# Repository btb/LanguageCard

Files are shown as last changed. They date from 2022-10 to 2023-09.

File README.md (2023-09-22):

# LanguageCard
 An Apple II Language Card. Based on a design by [iz8dwf](https://youtu.be/1KPIAoO1dTU)

[Interactive BOM](https://btb.github.io/LanguageCard/bom/LanguageCard_3.html)

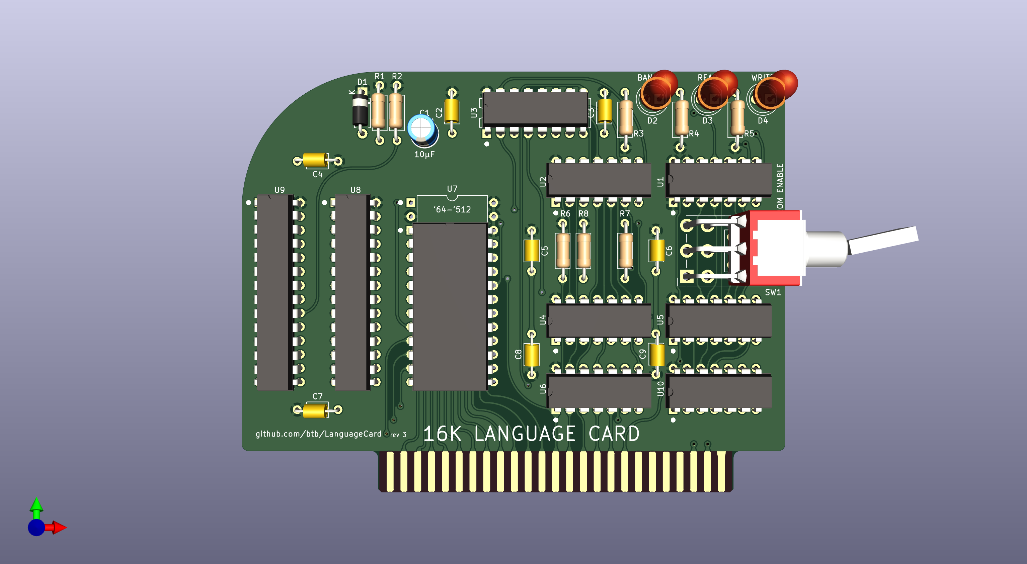
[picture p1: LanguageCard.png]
image info


## Description

This is a simple "language card" for the Apple II and II+, which expands the system from 48K to 64K by means of 16K of RAM, switchable into the address space normally used by the system firmware. That's two banks of 4K in the D0-D8 space, and one bank of 8K in the E0-F8 space. The C0-C8 space is not touched.

It uses static RAM so there is no need for the ribbon cable connecting it to the logic board that the original language cards had.

Like the original language cards, it can also contain a chip that will be used to replace the F8 ROM on your logic board. Additionally, you can enable or disable this replacement ROM with a switch or jumpers. If configured correctly, you can put two different F8 ROM images on a single chip and switch back and forth between them.

## Build Notes

### R3, R4, R5

Use higher resistance for	high-efficiency LEDs, e.g. 3.3K

### U8 and U9

Any narrow 8KBx8	static RAM can be used.	ex: 5C6408, Cy7C185, TC5588

### U7

Optional. 2K or larger	(E)EPROM for overriding the	logic board's F8 ROM. Enable	using SW1 or JP1.

### SW1

Optional Toggle switch. Miniature, Sub-miniature, or Ultra-miniature, right angle, SPDT. (Sub, Ultra-mini use JP1 pads)

An SPST switch which only closes the outer two pin positions can also work if you short JP3. 

To switch between two different F8 ROM images on a single 4K or greater chip, short JP2 and use a	DPDT switch instead - must be a three-position center OFF switch (ON-OFF-ON) in order to disable the card ROM and use the logic board F8 ROM.

### JP1

Enable and select which F8 ROM to use (if not using SW1)

| | |
|-|-|
|6|5|
|4|3|
|2|1|

No Jumpers: Card ROM disabled

#### Using a single ROM image:

JP2 open, Jumper on pins 1,3 (lower right): Card ROM enabled

#### Using two ROM images on a 4K or larger ROM:

JP2 shorted, Jumper on pins 1,3 (lower right) and 2,4 (lower left): Upper ROM image enabled (A11 high)

JP2 shorted, Jumper on pins 3,5 (upper right) and 4,6 (upper left): Lower ROM image enabled (A11 low)

### Solder Jumper JP2
Short, and install DPDT switch	(or use pair of jumpers as above) for	ability to select two different F8	ROM images on a single (4K or larger) ROM. 

### Solder Jumper JP3
Short if using an SPST switch	that only connects outer two pins

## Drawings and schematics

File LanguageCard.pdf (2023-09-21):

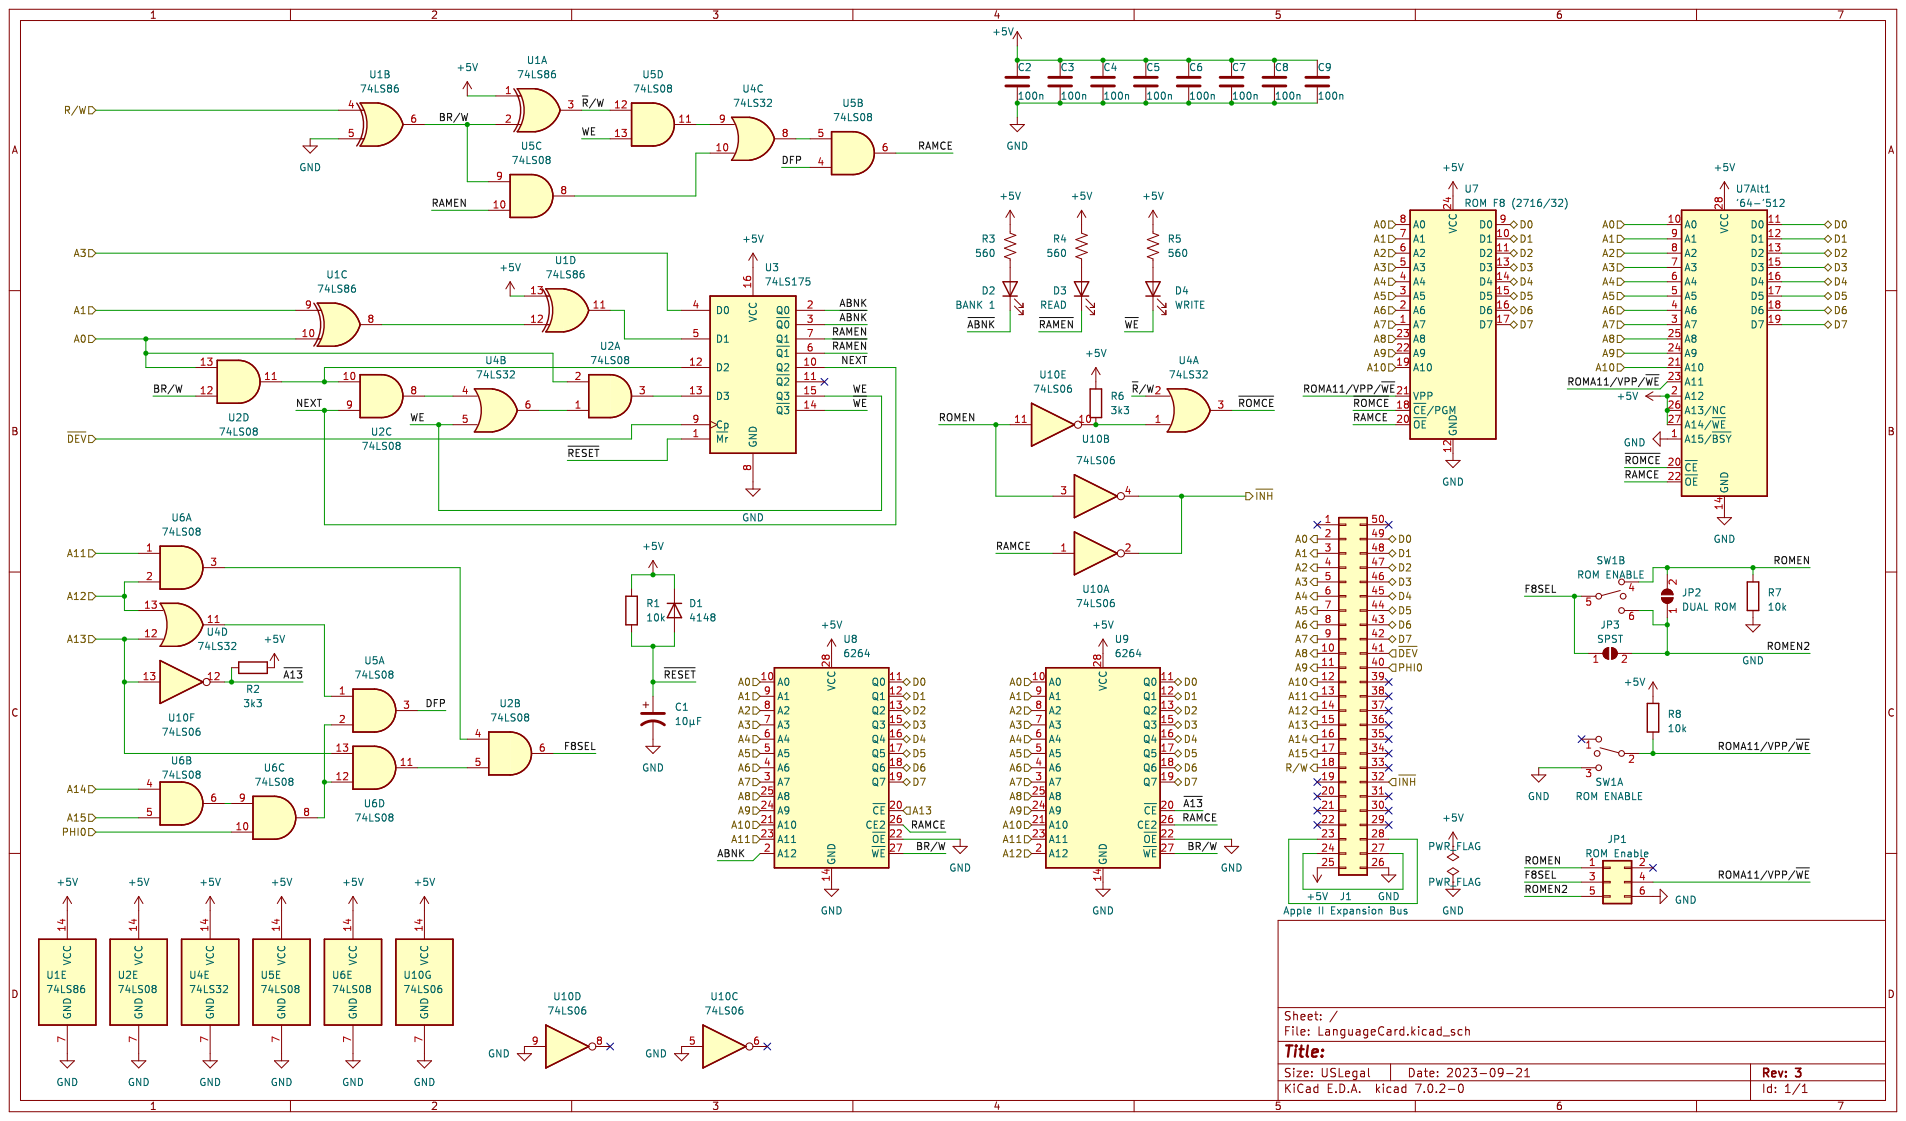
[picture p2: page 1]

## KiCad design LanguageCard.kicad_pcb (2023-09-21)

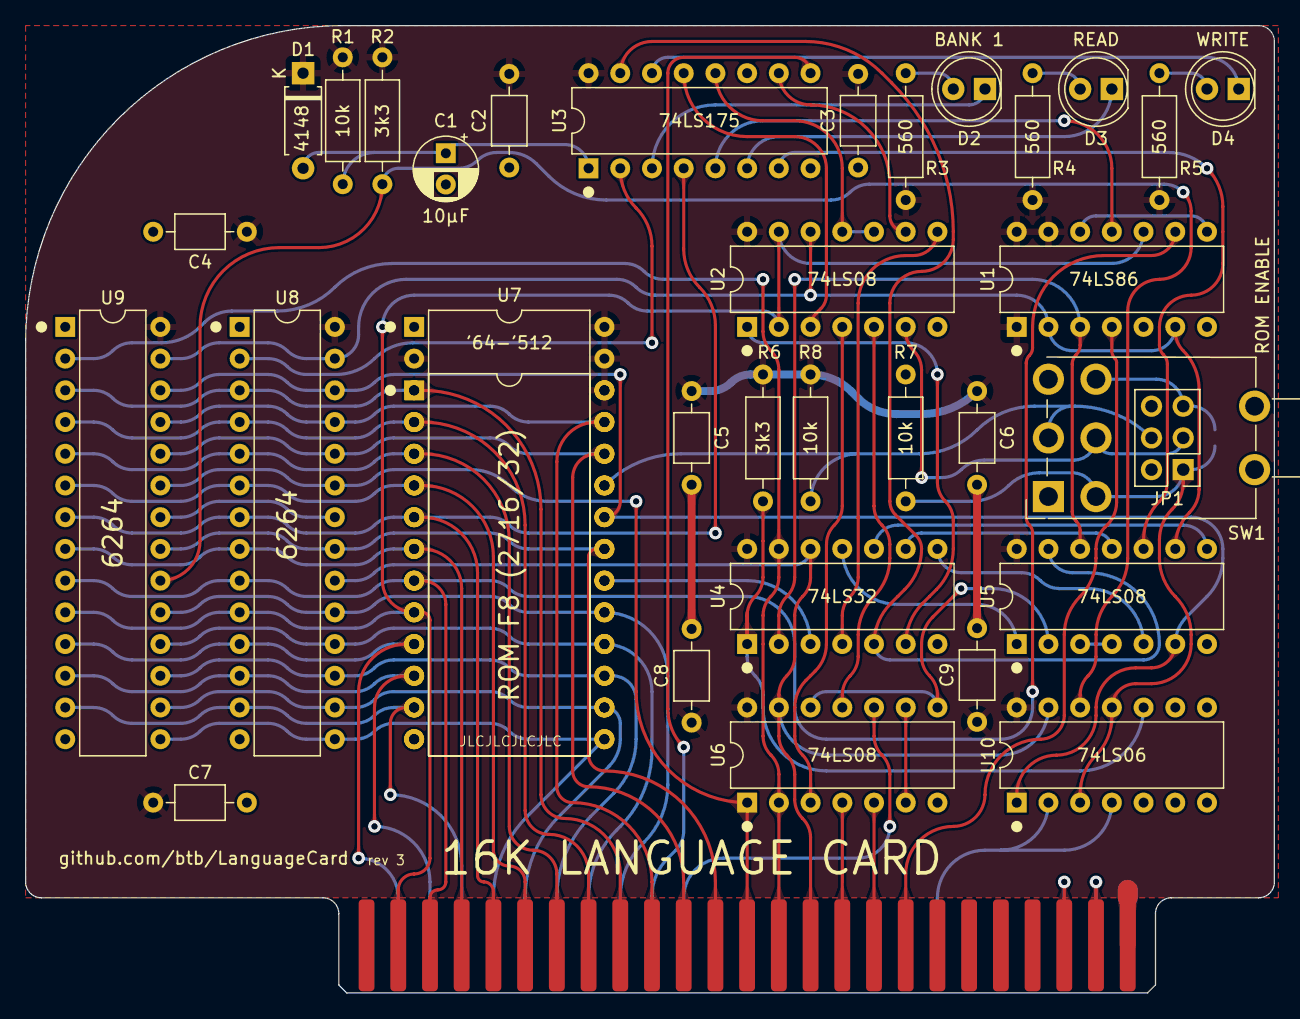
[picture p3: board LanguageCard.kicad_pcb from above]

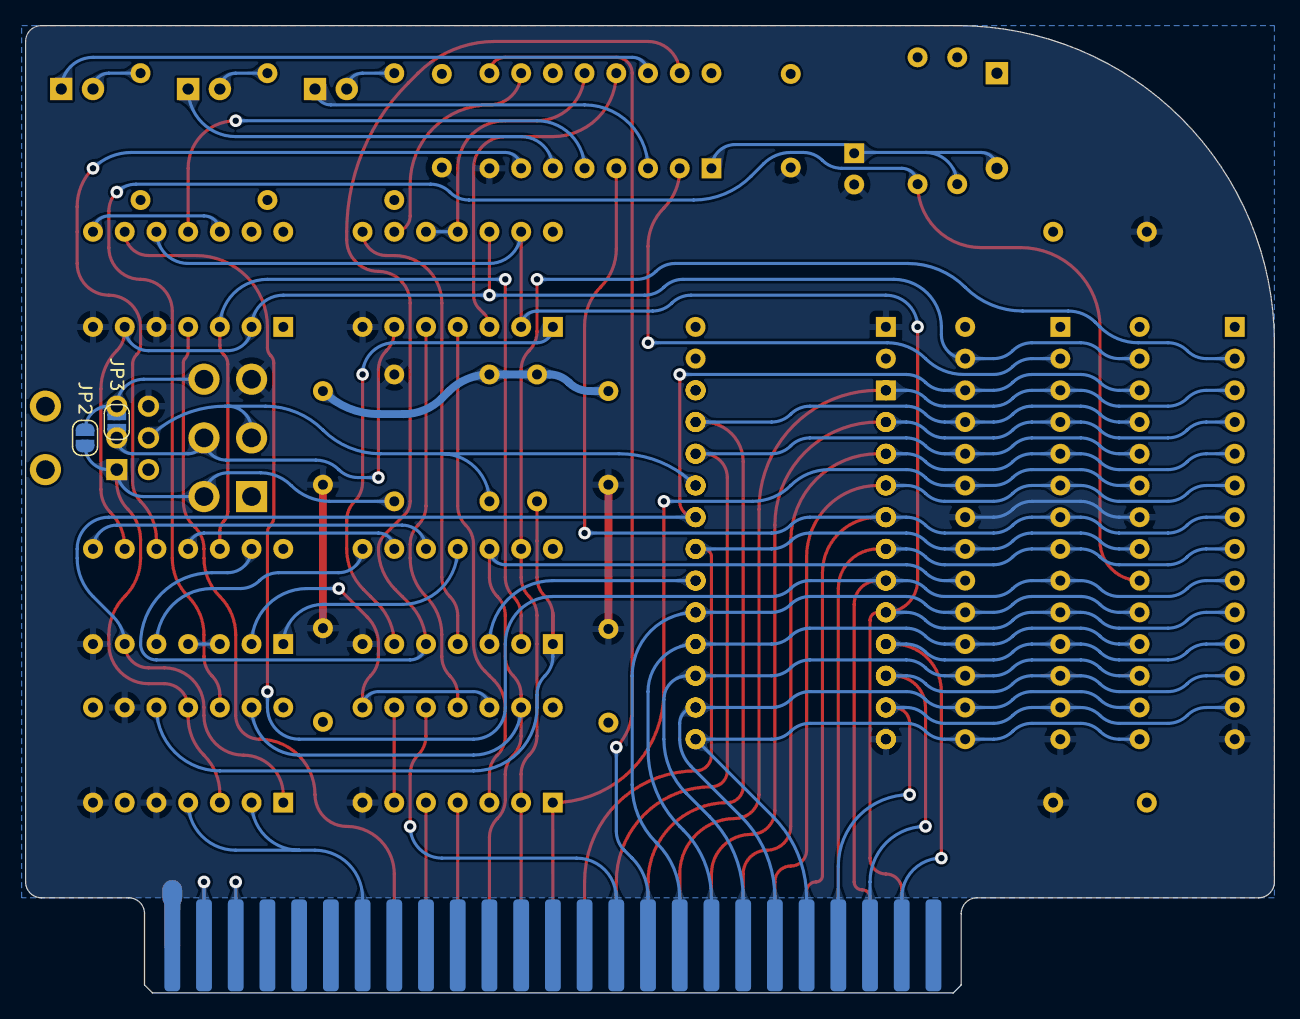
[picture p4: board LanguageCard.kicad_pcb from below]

Board: 2 copper layers, 100.0 x 77.5 mm, 37 parts (2 on the bottom side), 68 nets.

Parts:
C1: 10μF; CP_Radial_D5.0mm_P2.50mm
C2, C3, C4, C5, C6, C7, C8, C9: 100n; C_Axial_L3.8mm_D2.6mm_P7.50mm_Horizontal
D1: 4148; D_A-405_P7.62mm_Horizontal
D2: BANK 1; LED_D5.0mm
D3: READ; LED_D5.0mm
D4: WRITE; LED_D5.0mm
J1: Apple II Expansion Bus; Apple II Expansion Edge Connector
JP1: ROM Enable; PinHeader_2x03_P2.54mm_Vertical
JP2: DUAL ROM; SolderJumper-2_P1.3mm_Open_RoundedPad1.0x1.5mm
JP3: SPST; SolderJumper-2_P1.3mm_Open_RoundedPad1.0x1.5mm
R1, R7, R8: 10k; R_Axial_DIN0207_L6.3mm_D2.5mm_P10.16mm_Horizontal
R2, R6: 3k3; R_Axial_DIN0207_L6.3mm_D2.5mm_P10.16mm_Horizontal
R3, R4, R5: 560; R_Axial_DIN0207_L6.3mm_D2.5mm_P10.16mm_Horizontal
SW1: ROM ENABLE; SW_Lever_2P2T_Alcoswitch_AE203SD1
U1: 74LS86; DIP-14_W7.62mm
U2, U5, U6: 74LS08; DIP-14_W7.62mm
U3: 74LS175; DIP-16_W7.62mm
U4: 74LS32; DIP-14_W7.62mm
U7: ROM F8 (2716/32); DIP-24_W15.24mm
U7Alt1: '64-'512; DIP-28_W15.24mm
U8, U9: 6264; DIP-28_W7.62mm
U10: 74LS06; DIP-14_W7.62mm

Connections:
+5V: C2.2, C3.2, C4.1, C5.1, C6.1, C7.1, C8.1, C9.1, D1.1 (K), J1.25, R1.1, R2.2, R3.2, R4.2, R5.2, R6.2, R8.2, U1.1, U1.13, U1.14 (VCC), U2.14 (VCC), U3.16 (VCC), U4.14 (VCC), U5.14 (VCC), U6.14 (VCC), U7.24 (VCC), U7Alt1.2 (A12), U7Alt1.26 (A13/NC), U7Alt1.27 (A14/~WE), U7Alt1.28 (VCC), U8.28 (VCC), U9.28 (VCC), U10.14 (VCC)
/A0: J1.2, U1.10, U2.2, U2.13, U7.8 (A0), U7Alt1.10 (A0), U8.10 (A0), U9.10 (A0)
/A1: J1.3, U1.9, U7.7 (A1), U7Alt1.9 (A1), U8.9 (A1), U9.9 (A1)
/A2: J1.4, U7.6 (A2), U7Alt1.8 (A2), U8.8 (A2), U9.8 (A2)
/A3: J1.5, U3.4 (D0), U7.5 (A3), U7Alt1.7 (A3), U8.7 (A3), U9.7 (A3)
/A4: J1.6, U7.4 (A4), U7Alt1.6 (A4), U8.6 (A4), U9.6 (A4)
/A5: J1.7, U7.3 (A5), U7Alt1.5 (A5), U8.5 (A5), U9.5 (A5)
/A6: J1.8, U7.2 (A6), U7Alt1.4 (A6), U8.4 (A6), U9.4 (A6)
/A7: J1.9, U7.1 (A7), U7Alt1.3 (A7), U8.3 (A7), U9.3 (A7)
/A8: J1.10, U7.23 (A8), U7Alt1.25 (A8), U8.25 (A8), U9.25 (A8)
/A9: J1.11, U7.22 (A9), U7Alt1.24 (A9), U8.24 (A9), U9.24 (A9)
/A10: J1.12, U7.19 (A10), U7Alt1.21 (A10), U8.21 (A10), U9.21 (A10)
/A11: J1.13, U6.1, U8.23 (A11), U9.23 (A11)
/A12: J1.14, U4.13, U6.2, U9.2 (A12)
/A13: J1.15, U4.12, U6.13, U8.20 (~CE), U10.13
/A14: J1.16, U6.4
/A15: J1.17, U6.5
/ABNK: U3.2 (Q0), U8.2 (A12)
/BR/W: U1.2, U1.6, U2.12, U5.9, U8.27 (~WE), U9.27 (~WE)
/D0: J1.49, U7.9 (D0), U7Alt1.11 (D0), U8.11 (Q0), U9.11 (Q0)
/D1: J1.48, U7.10 (D1), U7Alt1.12 (D1), U8.12 (Q1), U9.12 (Q1)
/D2: J1.47, U7.11 (D2), U7Alt1.13 (D2), U8.13 (Q2), U9.13 (Q2)
/D3: J1.46, U7.13 (D3), U7Alt1.15 (D3), U8.15 (Q3), U9.15 (Q3)
/D4: J1.45, U7.14 (D4), U7Alt1.16 (D4), U8.16 (Q4), U9.16 (Q4)
/D5: J1.44, U7.15 (D5), U7Alt1.17 (D5), U8.17 (Q5), U9.17 (Q5)
/D6: J1.43, U7.16 (D6), U7Alt1.18 (D6), U8.18 (Q6), U9.18 (Q6)
/D7: J1.42, U7.17 (D7), U7Alt1.19 (D7), U8.19 (Q7), U9.19 (Q7)
/DFP: U5.3, U5.4
/F8SEL: JP1.3, JP3.1 (A), SW1.5 (B), U2.6
/NEXT: U2.9, U3.10 (Q2)
/PHI0: J1.40, U6.10
/RAMCE: U5.6, U7.20 (~OE), U7Alt1.22 (~OE), U8.26 (CE2), U9.26 (CE2), U10.1
/RAMEN: U3.7 (Q1), U5.10
/ROMA11/VPP/~WE: JP1.4, R8.1, SW1.2 (B), U7.21 (VPP), U7Alt1.23 (A11)
/ROMEN: JP1.1, JP2.2 (B), R7.2, SW1.4 (A), U10.3, U10.11
/ROMEN2: JP1.5, JP2.1 (A), JP3.2 (B), SW1.6 (C)
/R/W: J1.18, U1.4
/WE: U3.15 (Q3), U4.5, U5.13
/~A13: R2.1, U9.20 (~CE), U10.12
/~ABNK: D2.1 (K), U3.3 (~Q0)
/~DEV: J1.41, U3.9 (Cp)
/~INH: J1.32, U10.2, U10.4
/~RAMEN: D3.1 (K), U3.6 (~Q1)
/~RESET: C1.1, D1.2 (A), R1.2, U3.1 (~Mr)
/~ROMCE: U4.3, U7.18 (~CE/PGM), U7Alt1.20 (~CE)
/~R/W: U1.3, U4.2, U5.12
/~WE: D4.1 (K), U3.14 (~Q3)
GND: C1.2, C2.1, C3.1, C4.2, C5.2, C6.2, C7.2, C8.2, C9.2, J1.26, JP1.6, R7.1, SW1.3 (C), U1.5, U1.7 (GND), U2.7 (GND), U3.8 (GND), U4.7 (GND), U5.7 (GND), U6.7 (GND), U7.12 (GND), U7Alt1.1 (A15/~BSY), U7Alt1.14 (GND), U8.14 (GND), U8.22 (~OE), U9.14 (GND), U9.22 (~OE), U10.5, U10.7 (GND), U10.9
unnamed: D2.2 (A), R3.1
unnamed: D3.2 (A), R4.1
unnamed: D4.2 (A), R5.1
unnamed: J1.23, J1.28
unnamed: J1.24, J1.27
unnamed: R6.1, U4.1, U10.10
unnamed: U1.8, U1.12
unnamed: U2.1, U4.6
unnamed: U2.4, U6.3
unnamed: U2.5, U6.11
unnamed: U2.8, U4.4
unnamed: U1.11, U3.5 (D1)
unnamed: U2.10, U2.11, U3.12 (D2)
unnamed: U2.3, U3.13 (D3)
unnamed: U4.8, U5.5
unnamed: U4.9, U5.11
unnamed: U4.10, U5.8
unnamed: U4.11, U5.1
unnamed: U5.2, U6.8, U6.12
unnamed: U6.6, U6.9

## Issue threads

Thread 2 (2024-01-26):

Freezing

vibr77, 2024-01-26:
Hello Bradley,
Thanks for sharing your work,

I have ordered 5x of this card and it is not so easy to find the memory chip,
I replaced them by 2x AS7C164A-15PCN: SRAM SRAM SRAM, 64K, 8k x 8, 5v, 28pin Skinny P-DIP, 15ns

The pin setup seems to be the same,

However the card is not working and freezing when it tries to use the additional 16K.

How can I investigate what is wrong, do you have an idea.

Thanks

Vincent

amazingcobrazil, 2024-08-15:
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

I also built some boards for my Apple IIs and I'm having exactly the same problem:  freezing when I try to access the other 16KB of the board in ProDOS, for example. I'm using Cy7C185 on my boards. Have you made any progress in the tests?

vibr77, 2024-08-19:
Hello,
When I changed the Rom to a single rom chip (27C16) if I am not wrong it started working. I suspect that the legacy roms at too slow
V

From: amazingcobrazil ***@***.***>
Reply to: btb/LanguageCard ***@***.***>
Date: Friday 16 August 2024 at 00:06
To: btb/LanguageCard ***@***.***>
Cc: Vincent BESSON ***@***.***>, Author ***@***.***>
Subject: Re: [btb/LanguageCard] Freezing (Issue #2)

Hello Bradley, Thanks for sharing your work,

I have ordered 5x of this card and it is not so easy to find the memory chip, I replaced them by 2x AS7C164A-15PCN: SRAM SRAM SRAM, 64K, 8k x 8, 5v, 28pin Skinny P-DIP, 15ns

The pin setup seems to be the same,

However the card is not working and freezing when it tries to use the additional 16K.

How can I investigate what is wrong, do you have an idea.

Thanks

Vincent

I also built some boards for my Apple IIs and I'm having exactly the same problem: freezing when I try to access the other 16KB of the board in ProDOS, for example. I'm using Cy7C185 on my boards. Have you made any progress in the tests?

—
Reply to this email directly, view it on GitHub<https://github.com/btb/LanguageCard/issues/2#issuecomment-2292354358>, or unsubscribe<https://github.com/notifications/unsubscribe-auth/A4ZT7FMRD4JSO7TEPCT4WTTZRUQ5PAVCNFSM6AAAAABMS7I3IGVHI2DSMVQWIX3LMV43OSLTON2WKQ3PNVWWK3TUHMZDEOJSGM2TIMZVHA>.
You are receiving this because you authored the thread.Message ID: ***@***.***>

vibr77, 2024-09-25:
I still have the issue, I will try with old narrow SRAM to see if it change something of not

vibr77, 2024-09-30:
I change the SRAM by TC5588 and Cy7C185, it does not help, there is something else not working
Vincent

vibr77, 2024-10-03:
Based on all the test I have made this card is working without any issue 👍
- My Apple II ws having a bad DRAM chip causing freeze and data corruption,
- If you struggle to find SRAM for this card, you can use AS7C164A-15PCN it is working like a charm

I think we can close this issue

btb, 2024-10-13:
I'm glad to hear it. My apologies that I didn't get around to helping you with this

Closed 2024-10-03.

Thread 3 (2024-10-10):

Cy7C185 Incompatible pins?

DanielTelles91, 2024-10-10:
I am assembling the board but after analyzing the datasheet I noticed that the CY7C185 chip has a different pin position than the address line.
Can you please confirm if it is necessary to change the motherboard layout?

Thank you.

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

btb, 2024-10-13:
That wouldn't make a difference- since every location is essentially the same, it's pretty much arbitrary how they are numbered. Of course it would matter if this were a ROM - if you programmed it on one system and then moved it to another system with different addressing, the data would be scrambled.
Having said that - I know I bought some Cy7C185 chips to make sure it was 100% compatible, but I can't say for sure that I ever ended up testing those.

Closed 2024-10-21.

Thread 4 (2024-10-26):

incompatibility problem?

DanielTelles91, 2024-10-26:
Hello.
I built two boards (Rev. 2 and Rev. 3). Unfortunately I'm having problems with them. Several 64kb programs are crashing and the Apple II Confidence Program is showing an error:

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

All TTL are new and tested and the board was also tested.
The memory chip model is: CY7C185-25PC

I'm thinking it might be one of these problems:

1) The Apple II motherboard is Revision 0, could there be some incompatibility?

2) I'm using an adapter card for the system ROM, could there be some incompatibility?
https://www.blue-print.be/product-manuals/Manual-apple-ii-rom-replacement.pdf

I ran Adrian's Dead Test Memory program and it didn't find any errors in the main memory (48kb).
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

I appreciate your help in solving the problem.
Thank you
Daniel.

DanielTelles91, 2024-11-06:
The problem has been fixed.
The problem was the EPROM on the ROM Replacement Board. The EPROM was very slow (150ns) and was causing these problems. After replacing it with a 120ns the problem was solved.
Here's a tip for anyone having the same problem.
ROM Replacement Board: https://www.blue-print.be/product-manuals/Manual-apple-ii-rom-replacement.pdf

Thanks,
Daniel.

Closed 2024-11-06.

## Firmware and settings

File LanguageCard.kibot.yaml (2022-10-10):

kibot:
  version: 1

global:
  filters:
  - number: 1007
  - number: 1015
  - number: 58

filters:
- name: only_jlc_parts
  comment: Only parts with JLC (LCSC) code
  type: generic
  include_only:
  - column: LCSC#
    regex: ^C\d+

variants:
- name: place_holder
  comment: Just a place holder for pre_transform filters
  type: kicost
  pre_transform:
  - _kicost_rename
  - _rot_footprint

preflight:
  run_drc: true
  run_erc: true

outputs:
- name: basic_boardview
  comment: Board View export
  type: boardview
  dir: Assembly
- name: generic_bom_html
  comment: Generic Bill of Materials in HTML format
  type: bom
  dir: BoM/Generic
  options:
    format: HTML
    count_smd_tht: true
- name: generic_bom_csv
  comment: Generic Bill of Materials in CSV format
  type: bom
  dir: BoM/Generic
  options:
    format: CSV
    count_smd_tht: true
- name: generic_bom_txt
  comment: Generic Bill of Materials in TXT format
  type: bom
  dir: BoM/Generic
  options:
    format: TXT
    count_smd_tht: true
- name: generic_bom_tsv
  comment: Generic Bill of Materials in TSV format
  type: bom
  dir: BoM/Generic
  options:
    format: TSV
    count_smd_tht: true
- name: generic_bom_xml
  comment: Generic Bill of Materials in XML format
  type: bom
  dir: BoM/Generic
  options:
    format: XML
    count_smd_tht: true
- name: generic_bom_xlsx
  comment: Generic Bill of Materials in XLSX format
  type: bom
  dir: BoM/Generic
  options:
    format: XLSX
    count_smd_tht: true
- name: positional_bom_html
  comment: Positional Bill of Materials in HTML format
  type: bom
  dir: BoM/Positional
  options:
    format: HTML
    columns: &id001
    - Row
    - Description
    - Part
    - Part Lib
    - References
    - Value
    - Footprint
    - Footprint Lib
    - Quantity Per PCB
    - Build Quantity
    - Status
    - Datasheet
    - Sheetpath
    - Source BoM
    - Footprint X
    - Footprint Y
    - Footprint Rot
    - Footprint Side
    - Footprint Type
    - Footprint Populate
    - Footprint X-Size
    - Footprint Y-Size
    count_smd_tht: true
    html:
      style: modern-red
- name: positional_bom_xlsx
  comment: Positional Bill of Materials in XLSX format
  type: bom
  dir: BoM/Positional
  options:
    format: XLSX
    columns: *id001
    count_smd_tht: true
    xlsx:
      style: modern-red
- name: costs_bom_xlsx
  comment: Costs Bill of Materials in XLSX format
  type: bom
  dir: BoM/Costs
  options:
    format: XLSX
    count_smd_tht: true
    xlsx:
      style: modern-green
      kicost: true
      specs: true
    variant: place_holder
- name: macrofab_xyrs
  comment: Pick and place file, XYRS style
  type: bom
  options:
    variant: place_holder
    output: '%f_MacroFab.XYRS'
    units: mils
    group_fields: []
    sort_style: ref
    use_aux_axis_as_origin: true
    ignore_dnf: false
    footprint_populate_values: 0,1
    footprint_type_values: 1,2,0
    csv:
      separator: "\t"
      hide_pcb_info: true
      hide_stats_info: true
      hide_header: true
    columns:
    - field: References
      name: Designator
    - field: Footprint X
      name: X-Loc
    - field: Footprint Y
      name: Y-Loc
    - field: Footprint Rot
      name: Rotation
    - field: Footprint Side
      name: Side
    - field: Footprint Type
      name: Type
    - field: Footprint X-Size
      name: X-Size
    - field: Footprint Y-Size
      name: Y-Size
    - field: Value
    - field: Footprint
    - field: Footprint Populate
      name: Populate
  dir: Position
- name: basic_diff_pcb
  comment: PCB diff between the last two changes
  type: diff
  dir: diff
  layers:
  - layer: F.Cu
    suffix: F_Cu
    description: Front copper
  - layer: B.Cu
    suffix: B_Cu
    description: Bottom copper
  - layer: F.Silkscreen
    suffix: F_Silkscreen
    description: Front silkscreen (artwork)
  - layer: B.Mask
    suffix: B_Mask
    description: Bottom soldermask (negative)
  - layer: F.Mask
    suffix: F_Mask
    description: Front soldermask (negative)
  - layer: Edge.Cuts
    suffix: Edge_Cuts
    description: Board shape
  - layer: F.Courtyard
    suffix: F_Courtyard
    description: Front courtyard area
  - layer: F.Fab
    suffix: F_Fab
    description: Front documentation
  options:
    old: KIBOT_LAST-1
    old_type: git
    new: HEAD
    new_type: git
    cache_dir: /Users/bradleyb/Google Drive/workshop/Apple II/16k/LanguageCard/.cache
    add_link_id: true
- name: basic_diff_sch
  comment: Schematic diff between the last two changes
  type: diff
  dir: diff
  options:
    old: KIBOT_LAST-1
    old_type: git
    new: HEAD
    new_type: git
    cache_dir: /Users/bradleyb/Google Drive/workshop/Apple II/16k/LanguageCard/.cache
    add_link_id: true
    pcb: false
- name: basic_download_datasheets
  comment: Download the datasheets
  type: download_datasheets
  dir: Datasheets
- name: basic_dxf
  comment: Individual layers in DXF format
  type: dxf
  dir: Individual_Layers/DXF
  layers:
  - layer: F.Cu
    suffix: F_Cu
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

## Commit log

2022-08-03 Add KiCad files
    [LanguageCard.kicad_pcb, LanguageCard.kicad_sch]
2022-08-03 add schematic pdf and gerber files
    [LanguageCard-B_Cu.gbr, LanguageCard-B_Fab.gbr, LanguageCard-B_Mask.gbr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]
2022-08-06 Add interactive BOM
2022-08-07 Update BOM
    [LanguageCard.kicad_pcb, LanguageCard.kicad_sch]
2022-09-29 support larger SRAMS, minor updates
    [LanguageCard-B_Cu.gbr, LanguageCard-B_Fab.gbr, LanguageCard-B_Mask.gbr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]
2022-10-08 no, 32kx8 does not work. need two chip selects
    [LanguageCard-B_Cu.gbr, LanguageCard-B_Fab.gbr, LanguageCard-B_Mask.gbr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]
2022-10-08 add teardrops
    [LanguageCard-B_Cu.gbr, LanguageCard-B_Fab.gbr, LanguageCard-B_Mask.gbr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]
2022-10-08 fix up silkscreens and fabs
    [LanguageCard-B_Cu.gbr, LanguageCard-B_Fab.gbr, LanguageCard-B_Mask.gbr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]
2022-10-10 mark rev 0
    [LanguageCard-B_Cu.gbr, LanguageCard-B_Fab.gbr, LanguageCard-B_Mask.gbr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]
2022-10-10 update symbols
    [LanguageCard.kicad_pcb, LanguageCard.kicad_sch]
2022-10-10 doesn't really work that well yet
    [LanguageCard.kibot.yaml]
2022-10-10 just use a generic connector
    [LanguageCard.kicad_pcb, LanguageCard.kicad_sch]
2023-08-30 update to Kicad 7
    [LanguageCard.kicad_pcb, LanguageCard.kicad_sch]
2023-09-01 Larger ROM, enable switch
    [LanguageCard.kicad_pcb, LanguageCard.kicad_sch]
2023-09-02 dual rom config, lots of tweaks
    [LanguageCard.kicad_pcb, LanguageCard.kicad_sch]
2023-09-02 jlcpcb settings
    [LanguageCard.kicad_pcb]
2023-09-02 rev 2 gerbers
    [LanguageCard-B_Cu.gbl, LanguageCard-B_Fab.gbr, LanguageCard-B_Mask.gbs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]
2023-09-02 rev2 BOM
2023-09-04 add switch model and render
    [LanguageCard.kicad_pcb, LanguageCard.kicad_sch]
2023-09-21 rev 3
    [LanguageCard-B_Cu.gbl, LanguageCard-B_Cu.gbr, LanguageCard-B_Fab.gbr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]
